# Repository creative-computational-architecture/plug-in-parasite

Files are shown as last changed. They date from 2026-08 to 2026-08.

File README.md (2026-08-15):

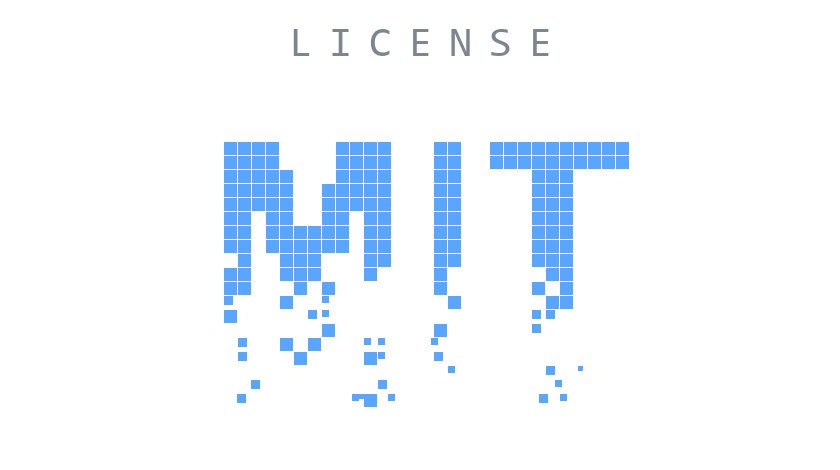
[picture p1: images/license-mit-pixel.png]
License: MIT


# Plug-in Parasite

*🇬🇧 English · [🇹🇷 Türkçe](README.tr.md)*

   

<p align="center">
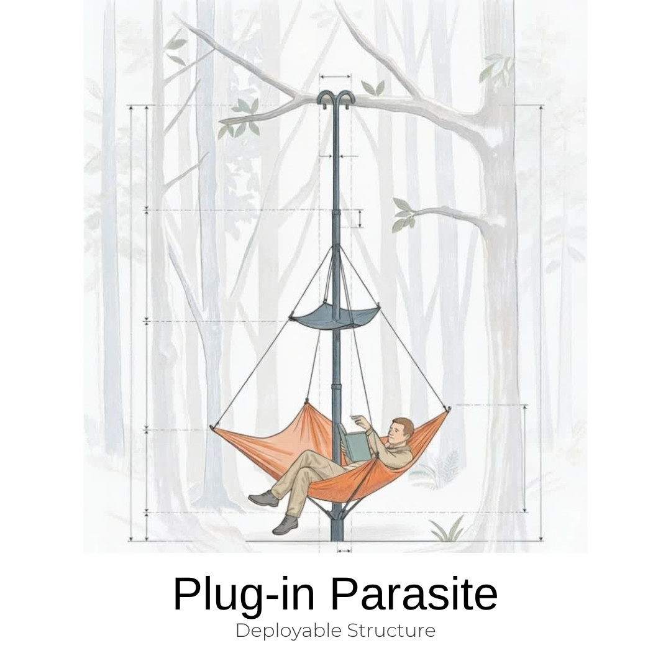
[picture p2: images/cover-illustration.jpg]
Plug-in Parasite — deployable structure, dimensioned cover illustration
  
</p>

> **The code in this repository is open-source under the [MIT License](LICENSE).** Fork it, run it, build on it. (Design assets, images and CAD models are CC BY-NC-SA 4.0 — see [License](#license).)

A parasitic, telescopic mast-tent — a portable shading/shelter structure that clamps onto urban street bollards or is staked into the ground. Folded, it is hand-carried. Deployed, it resembles a small ship's mast with two inverted-cone fabric canopies and a top sail.

**This is a real, open, in-development design — not a finished product and not a render exercise.** The concept and a physical maquette were made in a single night, then driven straight into a parametric model. It went through a full modelling-stack migration (Fusion 360 → Rhino 8 + Grasshopper) as the geometry logic matured, and the deployment film was curated down from ~40 AI video takes. We genuinely intend to build it — the socket, the telescopic mast, the whole thing — and the repository is shared in that spirit: to show the reasoning that got here, and to invite feedback, forks and manufacturing collaboration. Everything here is meant to keep evolving.

> **Authors / Context** — Creative Computational Architecture · Caglar Celik Architects (CCA). Concept and physical maquette developed 2026-05-16; parametric model built the same night with Claude as AI pair-modeller. Migrated to Rhino/Grasshopper 2026-05-17. Cinematic films generated with Seedance 2.0 / Kling 3.0. See [Tools & Credits](#tools--credits).
>
> *"Redefining space through computation."* — a design praxis studio working across analysis, mathematics, art, geometry, philosophy, aesthetics, architecture and technology.
>
> 📷 [Instagram @caglarcelikarchitects](https://www.instagram.com/caglarcelikarchitects) · [caglarcelik.works](https://caglarcelik.works)

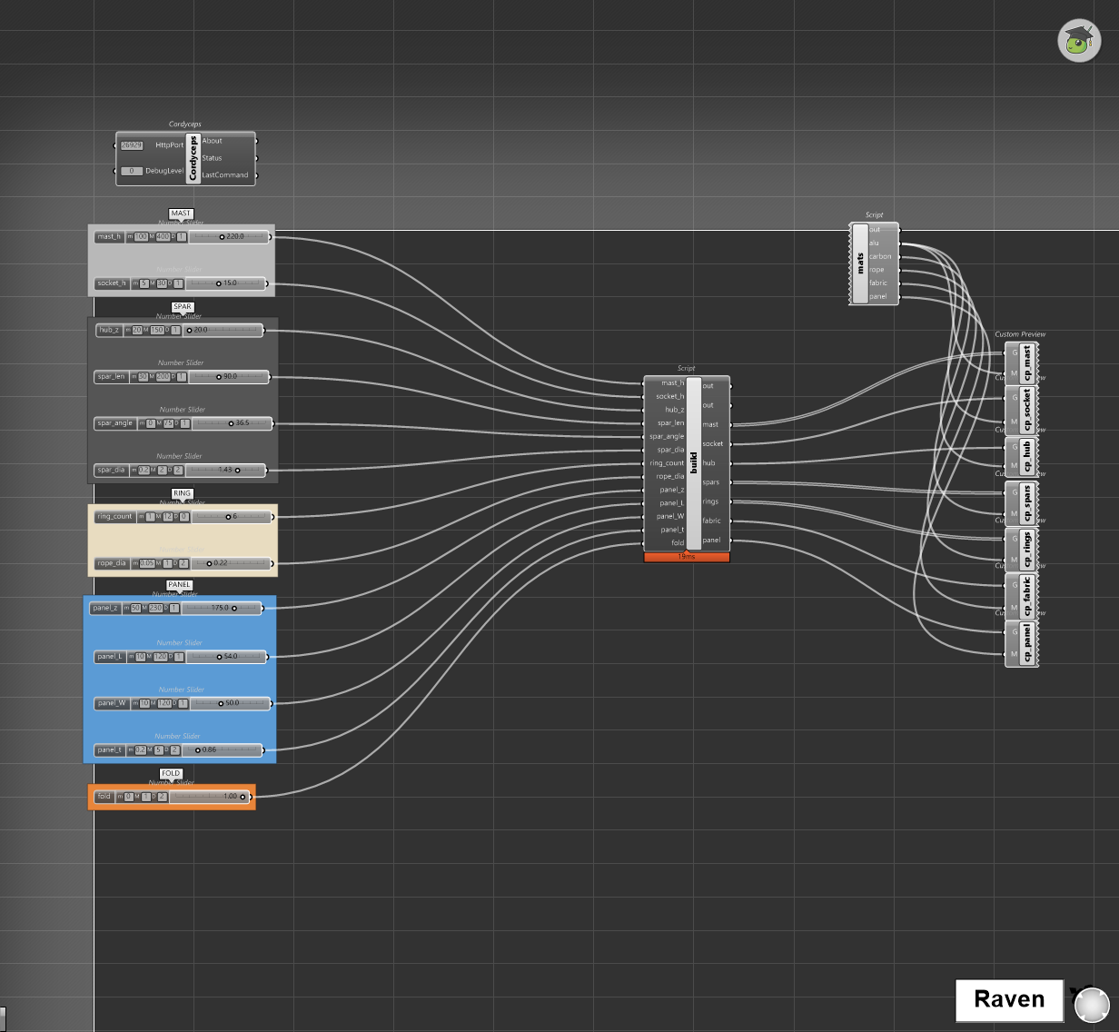
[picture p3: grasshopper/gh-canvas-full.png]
Grasshopper parametric definition — grouped parameters driving one build script and six geometry outputs


## Parametric System (Grasshopper)

The heart of this project is not the renders — it is the **parametric definition**. The whole structure is generated by a Grasshopper graph: a set of grouped sliders feed **one Python 3 build component** that emits six geometry sets. Change a slider, the whole shelter regenerates.

```
12 sliders (5 logical groups)                    →   build (Python 3)   →   6 geometry outputs
─────────────────────────────────────────────────────────────────────────────────────────────
MAST   : mast_h, socket_h                                                    mast    (3 telescopic tubes)
SPAR   : hub_z, spar_len, spar_angle, spar_dia                               socket  (bollard sleeve)
RING   : ring_count, rope_dia                                                hub     (spar clamp)
PANEL  : panel_z, panel_L, panel_W, panel_t                                  spars   (4 × swept up-and-out)
FOLD   : fold (0 = packed → 1 = deployed)                                    rings   (rope storage cage)
                                                                             panel   (diamond solar panel)
```

| | |
|---|---|
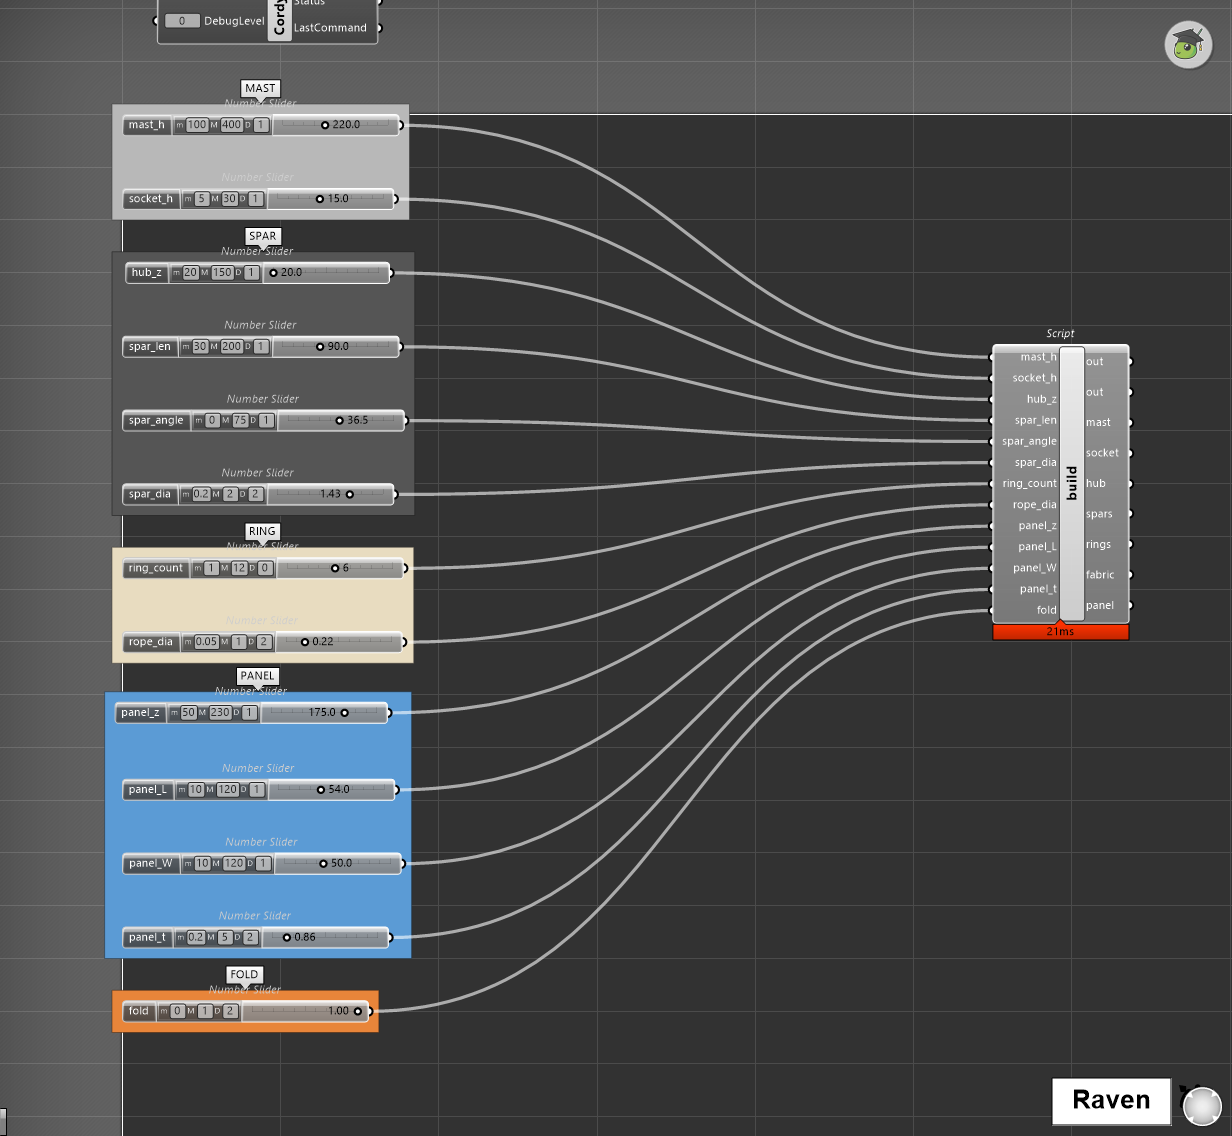
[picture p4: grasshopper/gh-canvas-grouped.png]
Colour-grouped parameter clusters
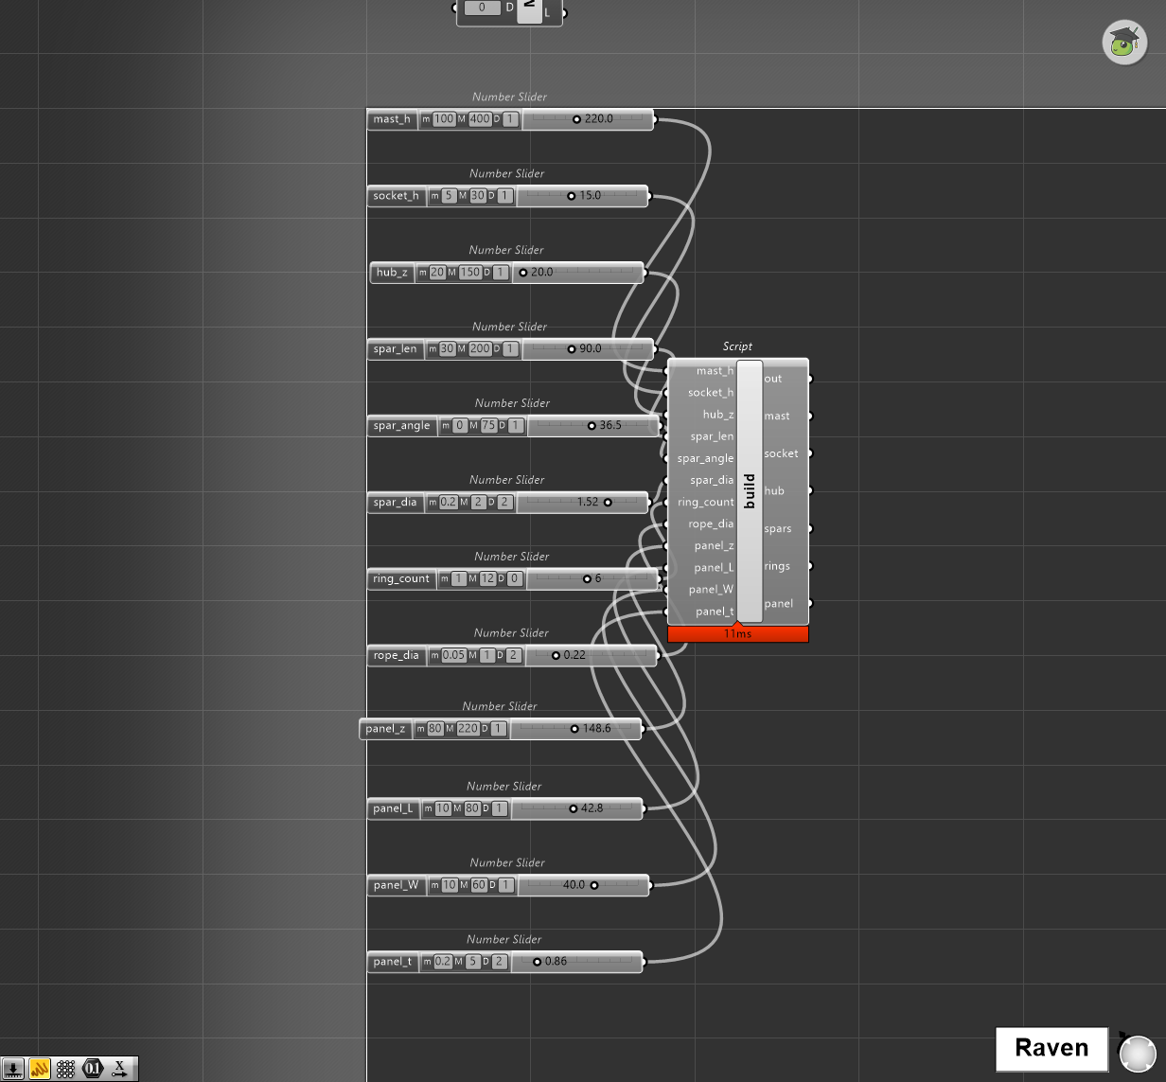
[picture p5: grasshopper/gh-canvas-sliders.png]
Slider column feeding the build component
|  |  |
| **Logical groups** — MAST / SPAR / RING / PANEL / FOLD, colour-coded on the canvas. | **One build component** — every slider wires into a single Python 3 script that returns the whole assembly. |

**Why it's built this way (the reasoning that got here):**

- **One driver, one script.** Rather than a sprawling web of native components, the geometry lives in a single readable Python 3 build script. The canvas stays legible; the *algorithm* carries the complexity. The per-stage logic is broken out for reference in [`cinematic/scripts/components/`](cinematic/scripts/components) — mast, hook, hub, spars, fabric hammock, panel canopy, storage rings, rigging ropes, carry strap.
- **A single `fold` parameter collapses the whole thing.** `fold` (0 → 1) is the deployment state: at 0 everything is packed inside the socket; at 1 it is the full 2.3 m rig. This is what makes it a *deployable* structure and not just a static model.
- **The design changed as the model matured — and the model shows it.** Two V1 ideas were deliberately replaced in V2, driven by the parametric work itself:
  - the rigid **upper fabric canopy → a diamond solar panel** (with a boolean-diff Ø30 mm mast hole);
  - the single-perimeter **diamond storage frame → a multi-ring "Chinese-lantern" cage** (`ring_count`, 1–12).
- **Edited programmatically.** The Grasshopper graph is driven by code through [Cordyceps](https://github.com/brookstalley/cordyceps), a Rhino 8 automation bridge — parametric edits are made programmatically, not by hand-dragging wires. This is the studio's tell: architecture built like software.

> Open `PlugInParasite.gh` in Rhino 8 Grasshopper to drive it live. `PlugInParasite.3dm` is the companion Rhino document.

---

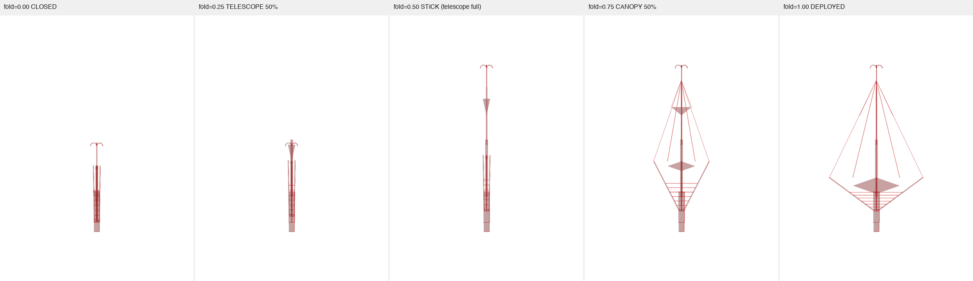
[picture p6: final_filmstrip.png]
Parametric fold sequence — fold 0 (closed) to 1 (deployed)


*One parameter, `fold`, drives the entire structure from packed to deployed:*
**`0.00` CLOSED → `0.25` TELESCOPE → `0.50` STICK → `0.75` CANOPY → `1.00` DEPLOYED.**

The same states, rendered — the wireframe above is not a drawing of an idea, it is the actual model output; below, the identical geometry with materials:

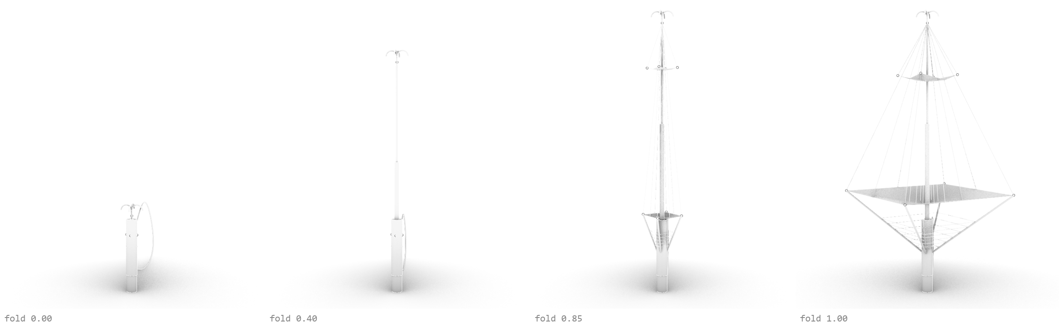
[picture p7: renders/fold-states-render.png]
Fold states rendered — white studio renders of the same four deployment states


---

## Deployment

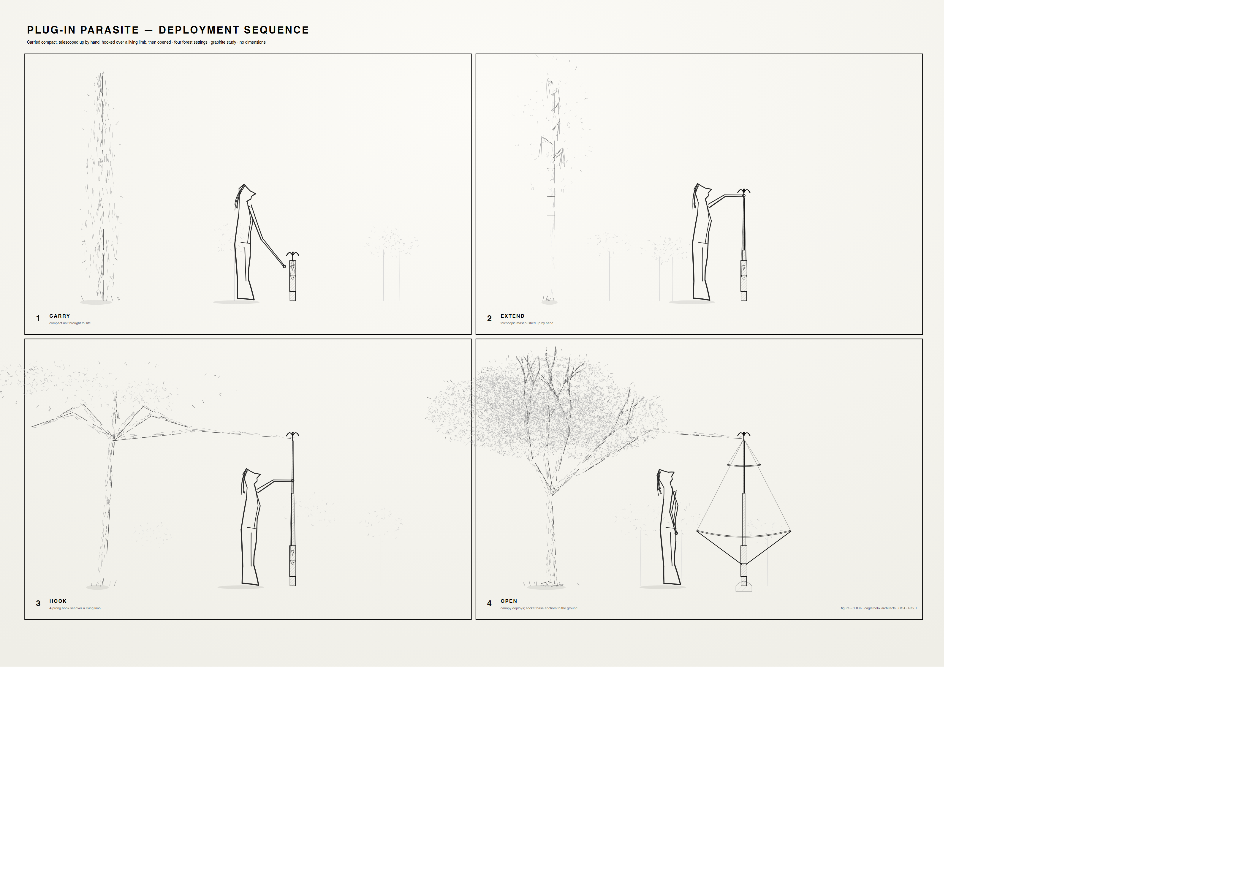
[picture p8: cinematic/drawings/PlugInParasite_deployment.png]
Deployment sequence — carry, extend, hook, open


*Hand-carried and compact → telescoped up by hand → hooked over a limb or plugged onto a bollard → canopy opened. One `fold` parameter drives the whole transition (see above).*

---

## Concept

The structure is designed around three states:

1. **Folded** — diamond-shaped, mast collapsed inside the socket, fabrics packed around the core. Hand-bag scale. *(the `fold=0` state)*
2. **Plugged onto a bollard** — the open base sleeve is dropped over a Ø80–100 mm street bollard, then the mast is telescoped upward and the canopies open. *Urban parking mode.*
3. **Staked into ground** — a pointed adapter screws into the base sleeve and is driven into soil. *Camping mode.*

The signature form is a **stack of two inverted cones** ("martini glass"): the lower wide canopy throws ground-level shade; the upper tier (now a solar panel) echoes a square-rigged ship's topsail. A small rectangular topsail and a pennant cap the rig.

<p align="center">
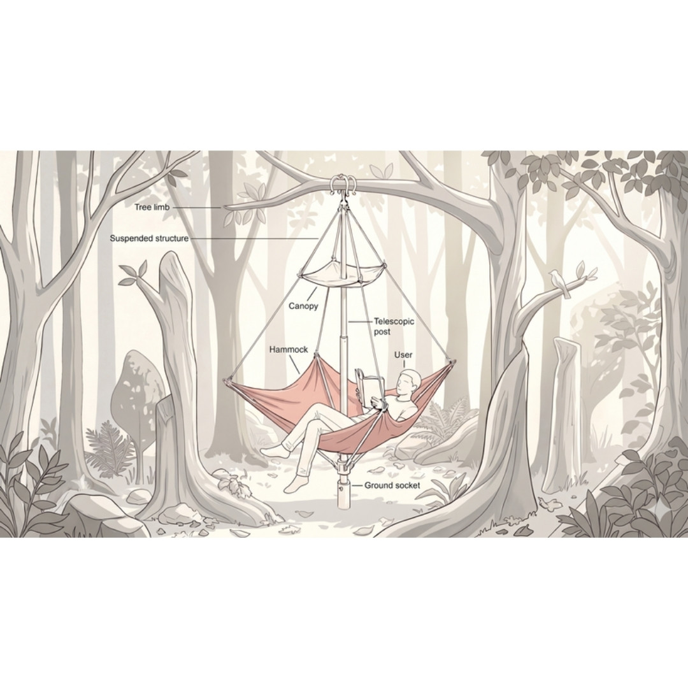
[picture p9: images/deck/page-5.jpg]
Annotated illustration — hammock, canopy, telescopic pole and ground socket labelled in the forest scene
  
</p>

*The inhabited state, annotated: hammock slung between the four spars, canopy above, telescopic pole, ground socket.*

---

## Components (Deployed)

Bottom-up, as generated by the Grasshopper build script:

| # | Component | Driven by | Description |
|---|---|---|---|
| 1 | **Socket** | `socket_h` | Two-bore sleeve: lower bore grips a Ø90 mm bollard, upper bore accepts the bottom mast segment. |
| 2 | **Mast** | `mast_h` | 3 telescopic aluminium tubes, OD Ø32 → Ø25 → Ø19 mm, 80 mm overlap per joint, fully extended 2.2 m. |
| 3 | **Hub** | `hub_z` | Single clamp hub on the mast that carries the four spars. |
| 4 | **Spars** | `spar_len`, `spar_angle`, `spar_dia` | Four rods springing **up and out**; tip reach sets the canopy footprint. |
| 5 | **Rings** | `ring_count`, `rope_dia` | 1–12 horizontal rope loops between adjacent spar tips — the "Chinese-lantern" storage cage. |
| 6 | **Panel** | `panel_z`, `panel_L/W/t` | Diamond solar panel with a boolean-diff Ø30 mm mast hole — replaced the V1 rigid upper canopy. |

Total deployed height ≈ 2.3 m. Folded target ≈ 0.7 m × 0.4 m × 0.15 m (hand-carry).

---

## Reference Material

The design started physical: a bamboo-and-thread maquette and a whiteboard full of iterations, the same night as the first model.

| | |
|---|---|
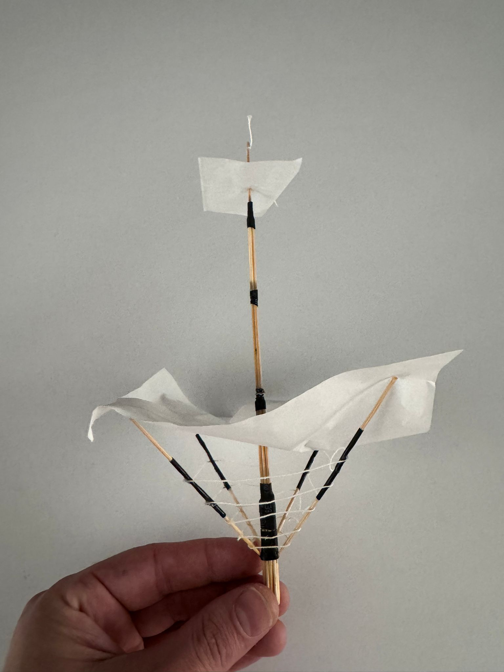
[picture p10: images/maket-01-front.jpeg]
maquette front
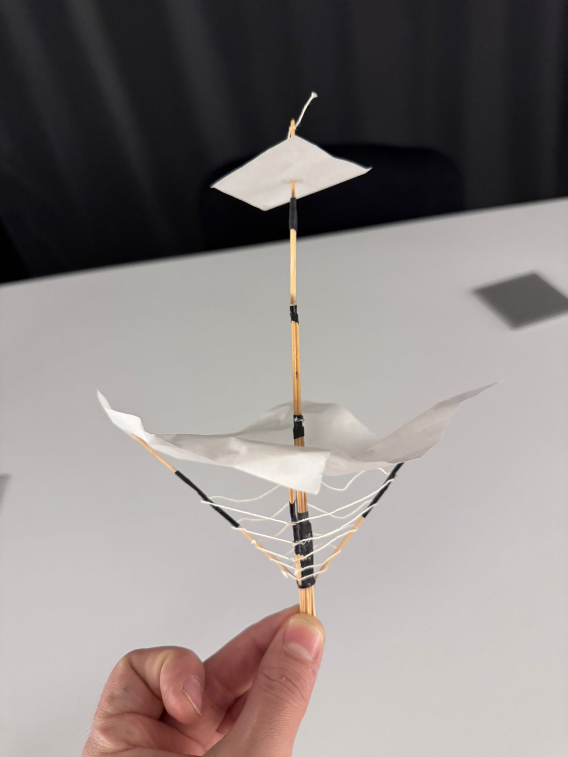
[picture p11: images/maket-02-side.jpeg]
maquette side
|  |  |
| Physical maquette — bamboo skewers, thread rigging, tissue-paper fabric. | Side view showing both canopies and the topsail. |
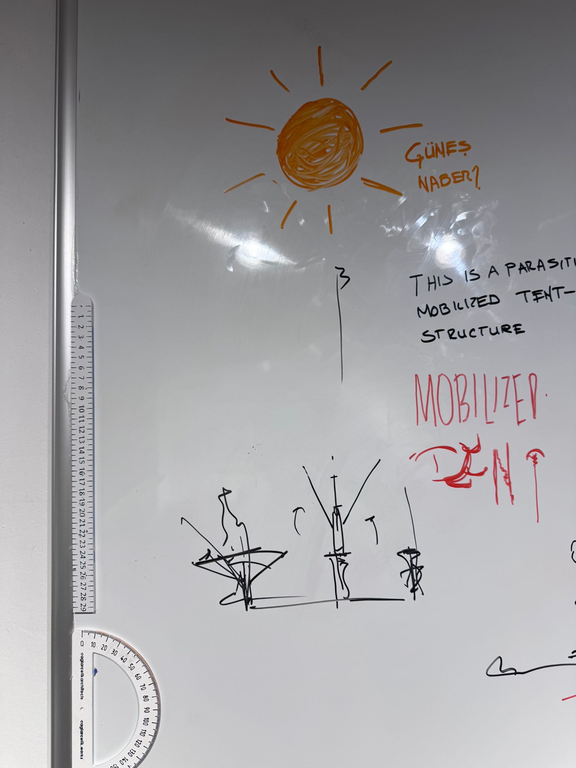
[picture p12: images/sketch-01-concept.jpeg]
whiteboard 1
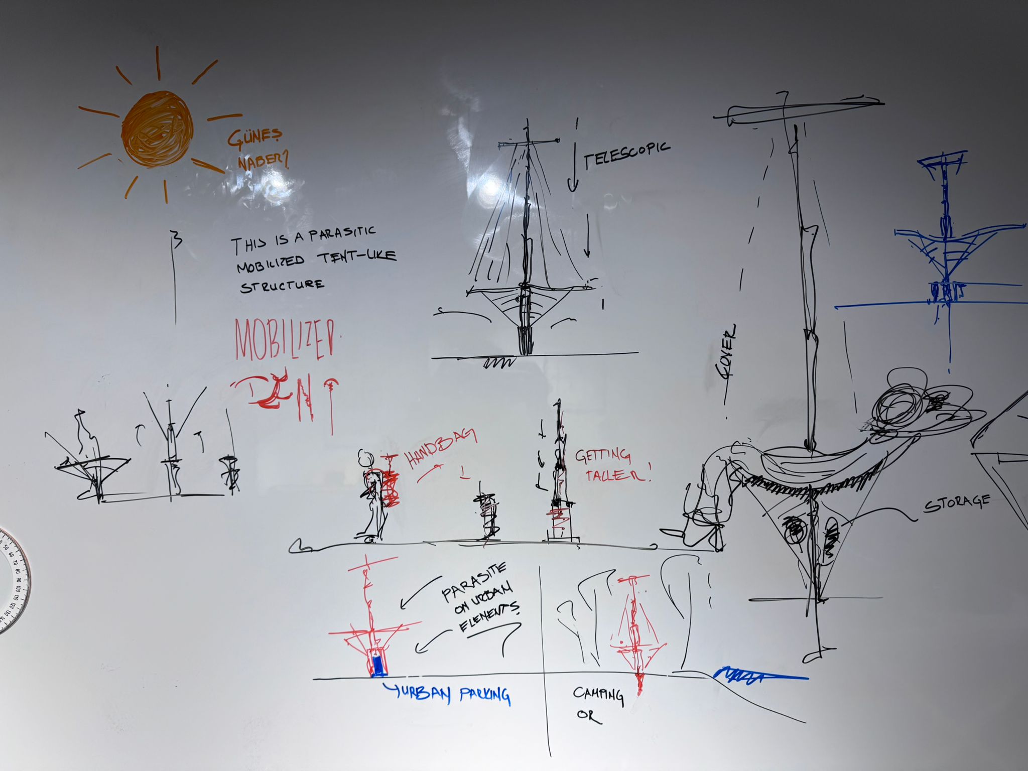
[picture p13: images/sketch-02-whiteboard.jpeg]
whiteboard 5
|  |  |
| Concept sketches: "Mobilized parasitic tent-like structure". | Full whiteboard with all the iterations. |
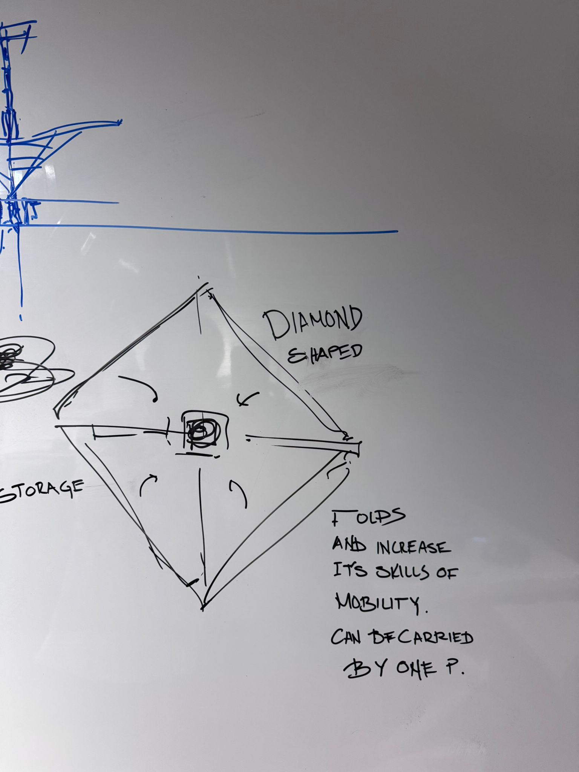
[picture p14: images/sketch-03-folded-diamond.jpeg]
diamond folded
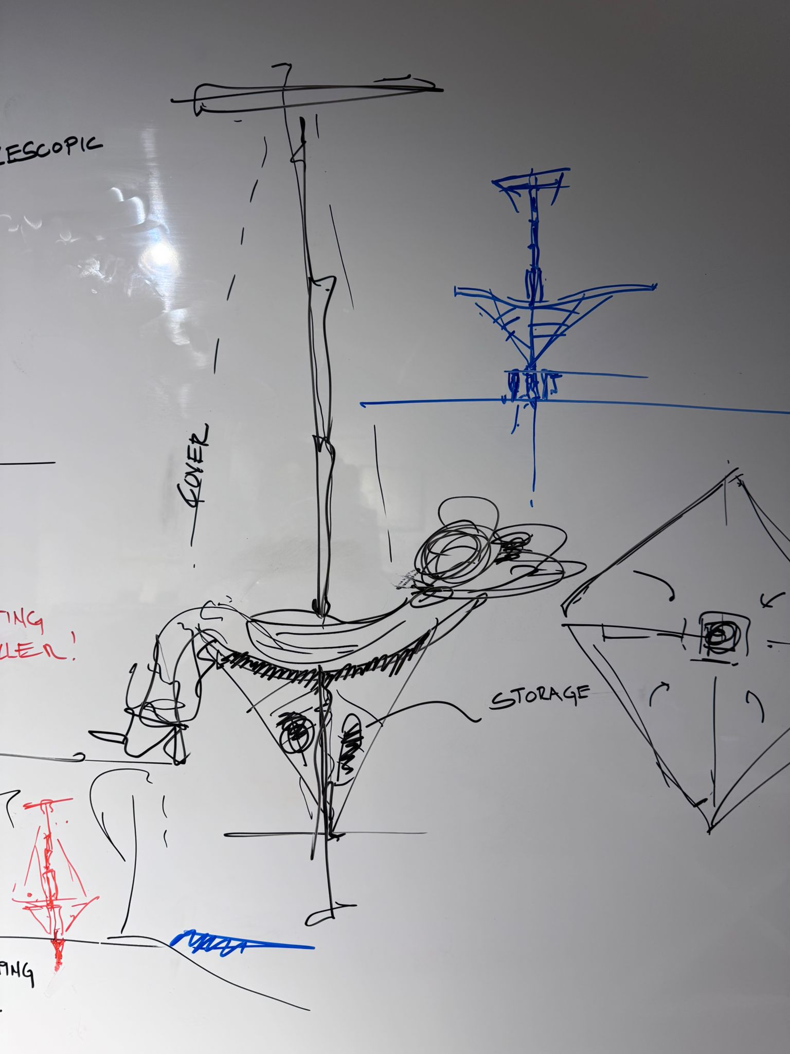
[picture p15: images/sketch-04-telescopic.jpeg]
telescopic detail
|  |  |
| Folded "diamond shape" state, with storage at the core. | Telescopic detail and rigging plan. |
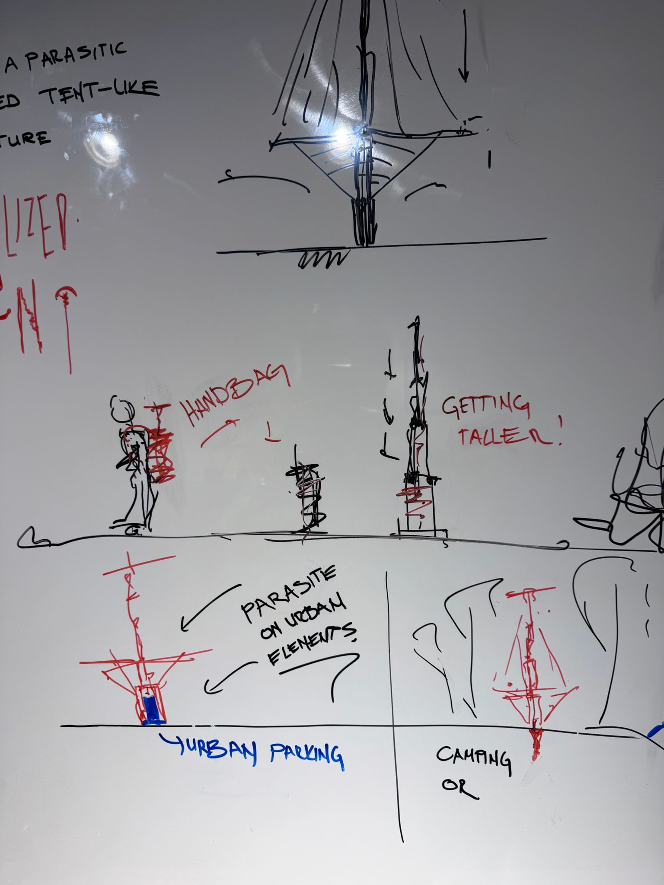
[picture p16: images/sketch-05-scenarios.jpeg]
urban + camping modes
|  |  |
| "Handbag → getting taller → parasite on urban elements / camping". | |

---

## Films

AI-cinematic shorts of the deployment sequence, built from the parametric model as reference imagery (image-to-video). These are the curated survivors of ~40 generations across Seedance 2.0 and Kling 3.0 — the shot list, prompts and edit pipeline are in [`cinematic/docs/`](cinematic/docs). Click to play on GitHub.

<p align="center">
  <a href="cinematic/films/PlugInParasite_process_reel.mp4">
    Process reel preview — renders, parametric canvas, illustrated storyboard
  </a>
</p>

*The process reel, playing inline — renders → parametric Grasshopper canvas → illustrated storyboard. Click it for the full-quality MP4 with sound.*

| File | What it shows |
|---|---|
| [`films/PlugInParasite_process_reel.mp4`](cinematic/films/PlugInParasite_process_reel.mp4) | **The process reel** — renders → parametric Grasshopper canvas → illustrated storyboard, in 20 seconds |
| [`films/PlugInParasite_deployment_FINAL_9x16.mp4`](cinematic/films/PlugInParasite_deployment_FINAL_9x16.mp4) | **Master cut** — full deployment story, vertical 9:16 |
| [`films/PlugInParasite_deployment_BLACK_v2_smooth_9x16.mp4`](cinematic/films/PlugInParasite_deployment_BLACK_v2_smooth_9x16.mp4) | Black carbon-fibre variant, smoothed master |
| [`films/PlugInParasite_WHITEFOAM_9x16.mp4`](cinematic/films/PlugInParasite_WHITEFOAM_9x16.mp4) | White-foam architectural maquette style |
| [`films/PlugInParasite_COVER_1960s_anim.mp4`](cinematic/films/PlugInParasite_COVER_1960s_anim.mp4) | Animated 1960s-style illustrated cover |
| [`films/PlugInParasite_annotated_walkthrough.mp4`](cinematic/films/PlugInParasite_annotated_walkthrough.mp4) | Annotated 3D component walkthrough — hook, panel, hammock, socket + telescopic mast (Turkish captions) |
| [`clips/`](cinematic/clips) | Individual shots: CARRY → SETDOWN → EXTEND → HOOK → OPEN → INHABIT → POV → FINALE |

### Presentation pages

The same story told across six media — cover illustration, photoreal film still, paper-craft maquette, product states, annotated scene, and the physical maquette on the whiteboard wall. Auto-advancing; stills in [`images/deck/`](images/deck).

<p align="center">
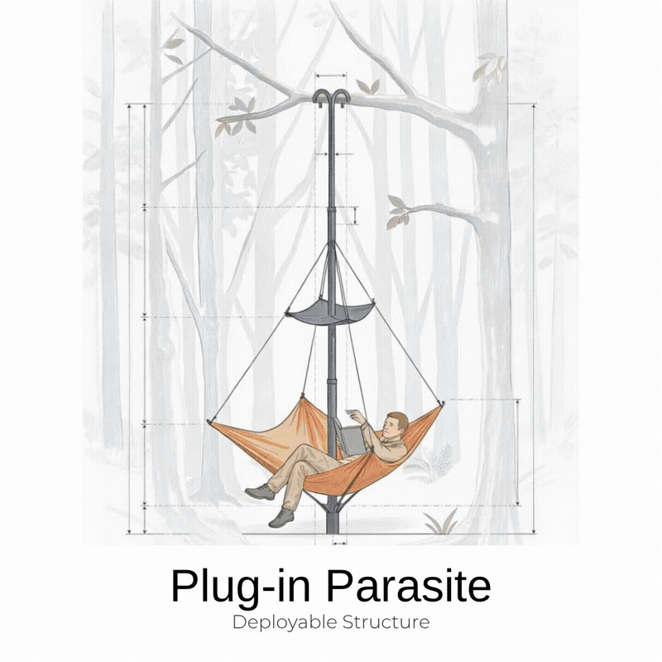
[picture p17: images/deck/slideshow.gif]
Presentation slideshow — six pages cycling automatically
  
</p>

---

## Renders & Drawings

Secondary to the parametric system, but included for reference: Fusion viewport captures and generated technical drawings (section 1:20, deployment sheet, branch detail — SVG/PNG/DXF plus the Python generators that draw them, in [`cinematic/drawings/`](cinematic/drawings)).

| Front | Iso | Right |
|---|---|---|
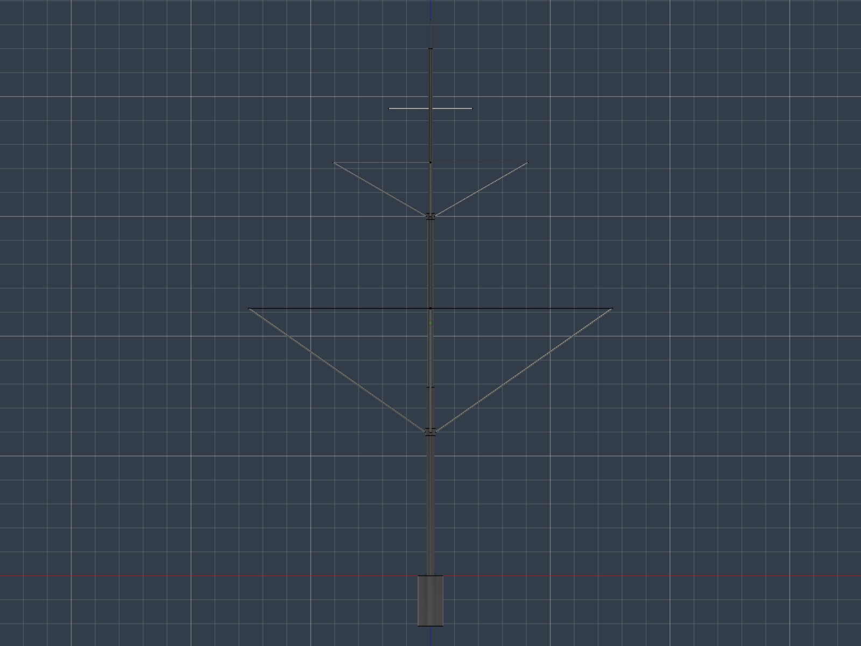
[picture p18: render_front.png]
front
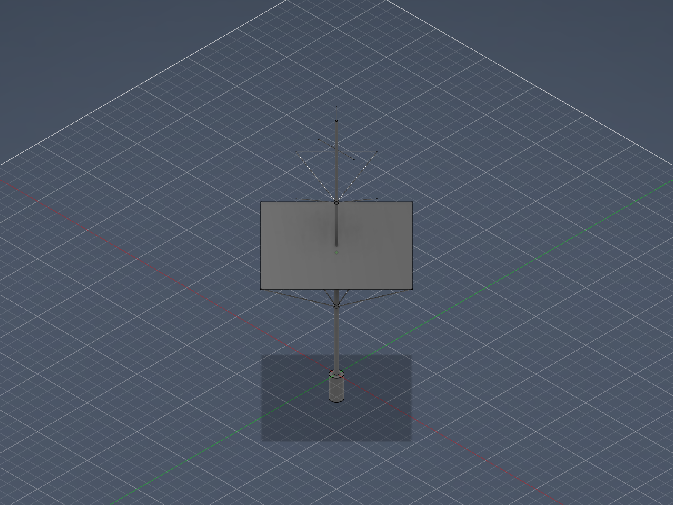
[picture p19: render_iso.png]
iso
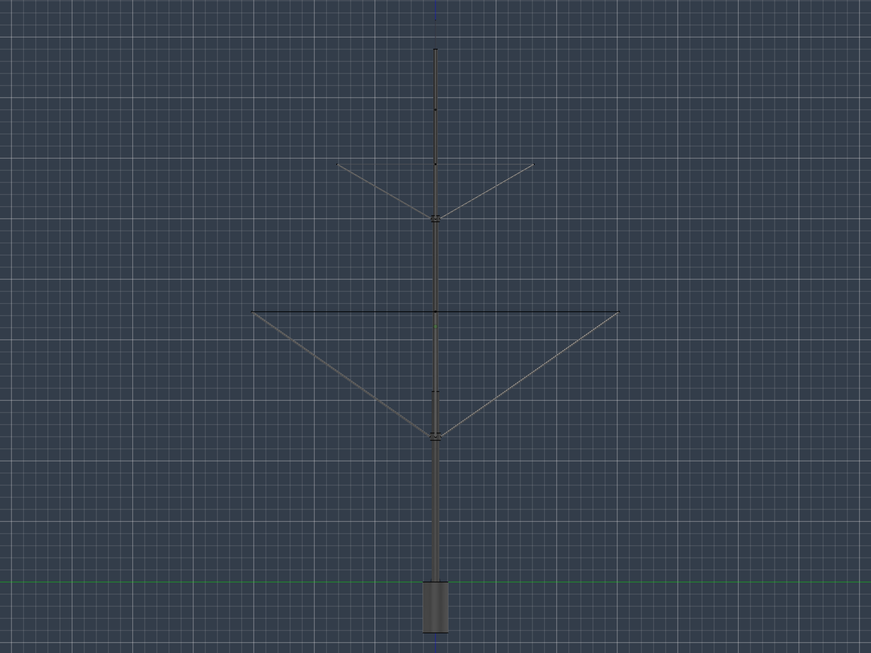
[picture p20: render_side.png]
side
|  |  |  |

---

## Parameters (reference values)

Current slider ranges and defaults on the Grasshopper canvas:

| Group | Slider | Range | Default |
|---|---|---|---|
| MAST | `mast_h` | 100–400 | 220 |
| MAST | `socket_h` | 5–30 | 15 |
| SPAR | `hub_z` | 20–150 | 20 |
| SPAR | `spar_len` | 30–200 | 90 |
| SPAR | `spar_angle` | 0–75° | 36.5 |
| SPAR | `spar_dia` | 0.2–2 | 1.45 |
| RING | `ring_count` | 1–12 | 6 |
| RING | `rope_dia` | 0.05–1 | 0.22 |
| PANEL | `panel_z` | 80–220 | 148.6 |
| PANEL | `panel_L` | 10–80 | 54 |
| PANEL | `panel_W` | 10–60 | 40 |
| PANEL | `panel_t` | 0.2–5 | 0.86 |
| FOLD | `fold` | 0–1 | 1 |

The Fusion V1 model exposes a larger set of 36 user parameters (mast tube diameters, wall thicknesses, sail rig, catenary rigging sag, etc.) — see [`cinematic/docs/GEOMETRY_SPEC.md`](cinematic/docs/GEOMETRY_SPEC.md) and `build_fusion_model.py`.

---

## Files

| Path | Purpose |
|---|---|
| `PlugInParasite.gh` | **Live parametric system** — Grasshopper definition (open in Rhino 8) |
| `PlugInParasite.3dm` | Companion Rhino 8 document |
| `PlugInParasite.f3d` | Archival — Fusion 360 V1 (36 parameters) |
| `PlugInParasite.step` | Cross-CAD STEP export (Rhino, SolidWorks, FreeCAD, …) |
| `build_fusion_model.py` | Standalone Fusion script that recreates the V1 model from scratch |
| `grasshopper/` | Canvas screenshots of the parametric definition |
| `cinematic/scripts/` | Per-stage GHPython component logic (the fold/deploy rig) |
| `cinematic/films/`, `clips/`, `concept_boards/` | Cinematic shorts, individual shots, AI concept boards |
| `cinematic/drawings/` | Technical drawings (SVG/PNG/DXF) + Python generators |
| `cinematic/docs/` | Geometry spec, storyboard, AI shot prompts, edit pipeline |
| `render_*.png`, `final_filmstrip.png` | Fusion viewport captures |
| `images/` | Source sketches + maquette photographs |

---

## Reproducing the Model

**Grasshopper (live):** open `PlugInParasite.gh` in Rhino 8, adjust any slider, geometry regenerates through the build component.

**Fusion V1 (from scratch):**

1. Fusion 360 → **File ▸ New Design**.
2. **Utilities ▸ ADD-INS ▸ Scripts and Add-Ins** (`Shift+S`).
3. Scripts tab → **`+`** → browse to `build_fusion_model.py` → **Run**.
4. The full model — parameters, all components, all bodies — appears in a few seconds.

---

## Roadmap (open — contributions welcome)

- **V2 — Folded state polish.** Verify the `fold=0` packed configuration reads as a clean hand-carry volume.
- ~~**Grasshopper migration.**~~ ✅ done — live parametric source of truth.
- ~~**Cinematic film.**~~ ✅ done — see [Films](#films).
- **V2 — Upper rigging & fabric drape.** Port the sail rig and lower-canopy fabric from the Fusion V1 into the Grasshopper script.
- **V3 — Cloth simulation.** Replace rigid loft surfaces with a draped cloth sim (Marvelous Designer / Houdini → back into GH).
- **V3 — FEA on socket.** Clamp force on the bollard and lateral stiffness under wind load.
- **Prototype (the real goal).** CNC-mill the aluminium socket and hubs; 3D-print hub clamp jaws; source carbon rod and rip-stop fabric; build and test a physical unit.

If you want to help make it real — manufacturing, materials, FEA, or just ideas — open an issue.

---

## Tools & Credits

Built with — and credit to — the following:

| Tool | Role |
|---|---|
| [Rhino 8](https://www.rhino3d.com/) + Grasshopper | Parametric geometry engine — the live model |
| [Cordyceps](https://github.com/brookstalley/cordyceps) | Rhino 8 automation bridge — programmatic Grasshopper editing |
| [Autodesk Fusion 360](https://www.autodesk.com/products/fusion-360/) | V1 solid model (36 parameters) |
| Claude / Claude Code (Anthropic) | AI pair-modeller — Python build logic, drawing generators, docs |
| [Higgsfield](https://higgsfield.ai/) | AI video generation platform |
| Seedance 2.0 · Kling 3.0 | Image-to-video models for the cinematic shots |
| Python 3 · ffmpeg | Geometry scripts and film edit pipeline |

Physical maquette, concept and design direction: Caglar Celik Architects.

---

## License

<p align="center">
  <picture>
    <source media="(prefers-color-scheme: dark)" srcset="images/brand/cca-mono-dark.svg">
    Creative Computational Architecture — CCA
  </picture>
  &nbsp;&nbsp;&nbsp;&nbsp;
  License: MIT
</p>

- **Code** (Python scripts, Grasshopper definition): [MIT](LICENSE).
- **Design, images, videos and CAD models**: [CC BY-NC-SA 4.0](https://creativecommons.org/licenses/by-nc-sa/4.0/) — share and adapt with attribution, non-commercial. For commercial use or manufacturing, contact the studio.

© 2026 Creative Computational Architecture — Caglar Celik Architects (CCA)

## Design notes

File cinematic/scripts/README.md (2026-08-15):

# Animation Rig Scripts (Rhino 8)

Python components that build the fold/deploy animation rig for the Track B clay renders.
Each file in `components/` is one stage of the parametric fold logic — mast, hook, hub,
spars, fabrics, straps — driven by a single `f_open` parameter (0 = folded, 1 = deployed).

## Usage

1. Open `PlugInParasite.3dm` in Rhino 8.
2. Run `setup_views.py` via `_-RunPythonScript` — it creates the named views
   (B1–B5 camera setups) used by the shot list.
3. Load the `components/*.py` files as GhPython components in Grasshopper
   (numbered in dependency order), wire `f_open` to a slider or animation driver.
4. Render frames per the edit pipeline in [`../docs/edit_pipeline_v2.md`](../docs/edit_pipeline_v2.md).

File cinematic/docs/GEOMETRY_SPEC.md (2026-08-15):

# PLUG-IN PARASITE — STRUCTURAL GEOMETRY SPEC (canonical, locked)

**Source of truth:** live Grasshopper model `PlugInParasite.gh` (fold slider GUID
`13550bea-2222-4361-a414-2a1fd2069271`; deployed = fold **1.0**). Measured
2026-06-24 from exact slider reads + baked-geometry bounding boxes.

> **RULE:** every render / AI image MUST match these proportions. Do **not**
> redesign, do **not** change any lengths, do **not** move GH sliders to "scale"
> the object for a scene — scale only in the prompt. The repeated failures came
> from (a) soft/ambiguous references and (b) ignoring the aspect ratio below.

Coordinate system: **Z-up, centimetres**, mast on the Z axis (x = y = 0), ground
plane at z = 0.

---

## GH parameters (deployed)

| param | value | meaning |
|---|---|---|
| `mast_h` | **220 cm** | telescopic mast full height |
| `socket_h` | **15 cm** | ground-anchor sleeve depth (z −15→0) |
| `panel_z` | **175 cm** | top canopy panel height |
| `panel_L × panel_W` | **54 × 50 cm** | canopy panel size |
| `panel_t` | 0.86 cm | canopy thickness |
| `spar_len` | **90 cm** | radial spar length |
| `spar_angle` | **36.5°** | spar splay (deployed) |
| `spar_dia` | 1.43 cm | spar tube diameter |
| `ring_count` | **6** | storage rings |
| `rope_dia` | 0.22 cm | rigging rope diameter (very thin) |
| `hub_z` | 20 | hub rise param |
| `fold` | **0 = folded · 0.5 = extended (canopy closed) · 1 = deployed** |

---

## Vertical stack (deployed, ground = z0)

1. **Socket** — z −15 → 0. Short ground-anchor sleeve the mast plugs into.
   **THE ONLY GROUND-CONTACT POINT, directly beneath the mast.** Nothing else
   touches the earth.
2. **Telescopic mast** — z 0 → 220. Slim vertical pole, **3 nested segments
   narrowing upward**: base seg ≈ Ø10 cm (z 0–50), mid ≈ Ø4 (z 42–135), top ≈ Ø2
   (z 127–220). Brushed aluminium.
3. **Bottom bed (hammock)** — 4 corners at **z 73.5**, reaching **±76.3 cm** on
   the X and Y axes (diamond / rotated-45° square, ~108 cm side). Warm-red
   (`#C43D1C`) ripstop fabric. Sits in the **lower third** (30 % of total height).
4. **6 storage rings** — z ≈ 19 → 50. Concentric horizontal rope rings around the
   lower mast, **below** the bed.
5. **Top canopy panel** — z **175**, **54 × 50 cm** near-horizontal flat cloth,
   upper third (70 % up). Rigging nodes at its 4 edge mid-points.
6. **Hook spire** — z 220 → 233.6. Central spire topped by **4 curved prongs**
   that splay to ±10.6 cm (**span ≈ 21 cm, ≈ 13 cm tall**). Steel. Hooks over a
   tree branch. *In renders show it clearly / slightly emphasised — it reads too
   small otherwise (user note).*

---

## PROPORTIONS / ASPECT RATIO — **LOCK THESE**

- Bounding box: **152.6 (W) × 152.6 (D) × 248.6 (H) cm**.
- **Front silhouette aspect  W : H ≈ 1 : 1.63** — the structure is **~1.6× TALLER
  than it is wide. Distinctly vertical / portrait.** Never squat.
- Mast (220) ≈ **1.44 × bed width** (152.6).
- Heights as fraction of total: bed **30 %**, canopy panel **70 %**, hook **100 %**.
  **Widest point = the bed** (lower third).
- Silhouette read: a slim vertical mast carrying a tall slender **DIAMOND / KITE**
  — rigging fans from the hook (top) down-and-out to the 4 bed corners (widest,
  lower third), then tapers back in to the socket.

---

## Rigging — **STRAIGHT tension lines (tensegrity)**

- **12 ropes**, very thin (Ø 0.22), from the spire/hook down to the canopy-panel
  nodes and the 4 bed corners.
- **Ropes are STRAIGHT, taut, in tension. Never curved, never slack, never
  lengthened.**
- Where a rope meets a **canopy-panel node, its axis does NOT change** — the line
  continues straight through the node (no kink / no direction break).

---

## Membrane (bed) sag

- The warm-red bed is a **shallow catenary** slung between the 4 corners at z 73.5.
- Ideal look = a **soft, comfortable sag** (like the first hero, occupied) — centre
  drops ≈ **25–40 cm** below the corner line. **NOT taut/flat, NOT extreme.**

---

## Recurring AI mistakes — DO NOT REPEAT

- Hook → 2-prong / anchor / too small. **Must be 4 splayed curved prongs, clearly
  visible.**
- Ropes → curved / slack / lengthened. **Keep straight & original length; no kink
  at nodes.**
- Ground contact → drifting off the mast. **Socket only, under the mast.**
- Proportions → squat / wide. **Hold 1 : 1.63 tall; slim mast taller than the bed
  is wide.**
- Storage rings dropped. **Keep all 6.**
- Soft/ambiguous reference (Arctic white-on-white). **Use the edged Technical
  render on grey as the primary lock.**

---

## Canonical reference renders — `geometry_ref/`

| file | state | use |
|---|---|---|
| `deployed_edged.png` | deployed, Technical **edged** (crisp boundaries) | **primary geometry lock** |
| `deployed_clay.png` | deployed clay on grey | solid form |
| `extended_clay.png` | fold 0.5 (mast up, canopy closed) | EXTEND / HOOK beats |
| `folded_clay.png` | fold 0 (compact column + 4-prong hook + strap + socket) | CARRY / SETDOWN beats |

Render recipe: Rhino display mode **Arctic** or **Technical** (edged) ·
background solid `#5D6B7A` · sun alt 40°/az 135° + skylight · `gh_document
capture_viewport` to a **non-Turkish path** (Turkish path fails). GH live preview
is NOT captured → **bake** the 9 geometry script components to a temp layer per
fold state, capture, then delete the layer and restore `fold` + show `PIP_compare`.

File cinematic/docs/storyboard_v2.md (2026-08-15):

# Plug-in Parasite — Cinematic Storyboard V2 (2026-05-28)

Updates the original `storyboard.md` for the current state: 10-component
GH canvas, V2.1 hammock, clay material on `#607080`, close-framing camera
(380,-180,280 → 0,0,120 lens 35mm), and a fresh 30s HERO render.

---

## What's already in `cinematic/shots_v2/`

| File | Source | Duration | Resolution | Notes |
|---|---|---:|---|---|
| `HERO_v11_30s.mp4` | render_queue_v2.py (550,-400,180) | 30s | 1280×720 | V12 close framing pending |
| `HERO_30s.mp4` (May 26) | V10 monolithic | 30s | 1280×720 | reference framing |
| `HERO_v4_30s.mp4` (May 26) | V10 earlier | 30s | 1280×720 | reference |
| `an1_rhino_animated.mp4` | Rhino animation export | 4s | 1500×1500 | square, user hand-animated |

> The "close-framing V12" render is in progress (background job
> `bfz2x1d3s`) — it will land at `cinematic/shots_v2/HERO_v12_30s.mp4`
> once ffmpeg composes the 720 PNGs.

## What's missing

- **Track A** (cinematic forest) — 3 atmospheric AI-generated shots
- **Final edit** — DaVinci timeline that interleaves Track A + clay
- **VO + music**

---

## Track A revised — 3 shots, ~$20 on Kling 2.0

**Bookend + hero structure-in-forest:**

```
0:00–0:05   A1  forest establishing               (empty, cinematic AI)
0:05–0:35   B   HERO_v12 30s deploy/retract cycle (clay)
0:35–0:40   A3  hero structure deployed in forest (image-to-video on
                                                   clay keyframe seed)
0:40–0:45   A2  pull-back forest reveal           (empty, cinematic AI)
```

Total **45 seconds**. Cinematic establishing → clay mechanics → hero
in nature → cinematic closure. A3 is the bridge that places the
parasol in its real environment; using image-to-video on a clay
keyframe locks the geometry so Kling doesn't hallucinate the structure
into something else.

If A3 is too hard or budget is tight, fall back to the simpler 3-cut
bookend (drop A3, total 40s) — `track_a_prompts_v2.md` Path 1 vs Path 2
section explains the trade-off.

### A1 — Forest establishing (0:00–0:05)

**Goal:** atmospheric setup. The viewer lands in a peaceful temperate
forest. No structure visible yet. A slow forward dolly draws them in.

**Tool:** Kling 2.0 (Pro), text-to-video.

**Prompt:**
```
Cinematic morning shot in a temperate deciduous forest. Soft sunlight
streaming through tall beech and oak trees, dappled light spots on
the forest floor. Wide-angle establishing shot. Slow forward dolly
movement, very gentle. Light mist near the ground. No people, no
animals. Realistic, just after sunrise. Cinematic depth of field,
shallow focus on a single tree trunk in foreground. Anamorphic lens
look, slight film grain. 16:9, 5 seconds.
```

**Negative:** people, person, human, figure, animals, deer, text, logo,
watermark, blur, overexposed, cartoon, illustration, drone shot.

**Output:** `shots_A/A1_forest_establishing.mp4` (1920×1080, 5s).

### A2 — Pull-back reveal (0:35–0:40)

**Goal:** scale + closure. The camera pulls back from a quiet forest
clearing where the deploy-then-retract cycle just happened. Empty,
serene, "just-departed" feeling. No structure required in this
shot — the cut before is the structure folding back into its bag.

**Prompt:**
```
Cinematic wide pull-back shot from forest clearing outward into a vast
quiet temperate forest. Slow continuous camera retreat. Late morning
light, golden tones, mist between distant trees. Empty clearing
visible center-frame. No people, no objects, no equipment. Realistic,
anamorphic, slight film grain. End on a still wide composition,
20-30% sky visible above tree line. 16:9, 6 seconds.
```

**Negative:** same as A1, plus "tent, camping equipment, structure,
tower, post."

**Output:** `shots_A/A2_pullback.mp4` (1920×1080, 6s — trim to 5s).

---

## Submission checklist for Kling

1. Account: <https://klingai.com> — starter pack ~$10 = 660 credit
2. Pro mode ~70 credit per shot. 2 shots × 3 attempts each = 420 credit
3. Settings per shot:
   - **Mode:** Pro
   - **Aspect:** 16:9
   - **Duration:** 5s (A1) or 6s (A2)
   - **Camera:** Forward Dolly (A1), Pull Back (A2)
   - **Style:** Cinematic
4. **Try 2-3 generations per shot, save all** — pick the best take in
   DaVinci, keep the others as reference.
5. **Download:** original quality MP4, no watermark (paid mode).

---

## Alternative: skip Kling entirely

If you want zero AI cost, the clay HERO is portfolio-ready as-is once
the V12 close-framing render lands. Add:
- 2-sec title card at start (project name + cca-architects)
- 2-sec end card (year + collaborators)
- Soft ambient music (Suno / Epidemic Sound)

Total ~34 sec, portfolio-grade, $0 AI spend.

---

## Files

- `storyboard.md` — original 6-cut hybrid plan (reference)
- `storyboard_v2.md` — this file
- `track_a_prompts.md` — prompts for full 3-shot version
- `track_b_shotlist.md` — clay shot inventory
- `vo_script.md` — EN voiceover + TR subtitle
- `edit_pipeline.md` — DaVinci + ffmpeg notes
- `shots_v2/HERO_v12_30s.mp4` — the new clay hero (in progress)
- `shots_A/` — empty, AI shots land here after Kling generation

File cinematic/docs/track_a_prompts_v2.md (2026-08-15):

# Track A Prompts V2 — paste-ready Kling submission

Three shots for the cinematic wrapper:

- **A1** — empty forest establishing (atmosphere setup, no structure)
- **A2** — empty forest pullback (closure, no structure)
- **A3** — **structure deployed in forest** (full description, hung from tree)

A1 and A2 are deliberately empty so Kling's hallucination risk stays
contained. A3 is the hero "in the wild" shot — it describes the
parasol explicitly: vertical mast, 4-prong curl hook at top hooking
around a tree branch, hanging hammock seat below, small flat canopy
above, tensile rigging ropes, storage ring frame around the lower
mast. Best run as **image-to-video** with a clay HERO keyframe as
the seed so Kling has the geometry locked in visually.

Total ~$15-25 at Kling Pro depending on how many re-rolls A3 needs.

> Rules across all three shots: **no people, no figures, no equipment**
> other than the parasol itself.

---

## A1 — Forest Establishing (5 seconds)

**Settings (klingai.com):**
- Mode: **Pro**
- Aspect: **16:9**
- Duration: **5s**
- Camera: **Forward Dolly Slow**
- Style: **Cinematic**

**Prompt:**
```
Cinematic morning shot in a temperate deciduous forest. Soft sunlight
streaming through tall beech and oak trees, dappled light spots on
the forest floor. Wide-angle establishing shot. Slow forward dolly
movement, very gentle. Light mist near the ground. No people, no
animals. Realistic, just after sunrise. Cinematic depth of field,
shallow focus on a single tree trunk in foreground. Anamorphic lens
look, slight film grain.
```

**Negative prompt:**
```
people, person, human, figure, animals, deer, text, logo, watermark,
blur, overexposed, cartoon, illustration, drone shot, top-down, snow
```

**Try count:** generate 3, pick best (mist consistency + dappled light
pattern matter most). Save the runners-up in `shots_A/A1_v01.mp4`,
`A1_v02.mp4`, etc. before deciding.

**Save as:** `cinematic/shots_A/A1_forest_establishing.mp4`

---

## A2 — Pull-back Reveal (6 seconds)

**Settings:**
- Mode: **Pro**
- Aspect: **16:9**
- Duration: **6s**  (trim to 5s in edit)
- Camera: **Pull Back**
- Style: **Cinematic**

**Prompt:**
```
Cinematic wide pull-back shot from forest clearing outward into a vast
quiet temperate forest. Slow continuous camera retreat. Late morning
light, golden tones, mist between distant trees. Empty clearing
visible center-frame. No people, no objects, no equipment. Realistic,
anamorphic, slight film grain. End on a still wide composition,
20-30% sky visible above tree line.
```

**Negative prompt:**
```
people, person, human, figure, animals, vehicles, text, logo,
watermark, drone shot, top-down, tent, camping equipment, structure,
tower, post, building, snow, rain
```

**Try count:** 3 generations. The "empty clearing center-frame" is the
hard constraint — if Kling hallucinates a structure in the middle,
re-roll.

**Save as:** `cinematic/shots_A/A2_pullback.mp4`

---

---

## A3 — Hero in Forest (5 seconds, image-to-video PREFERRED)

This is the shot where the AI needs to know what the structure is.
Two paths; **path 1 (image-to-video) is strongly preferred** because it
locks in the geometry from a real render.

### Structure description (used in BOTH paths)

The parasol is a minimalist white plaster-finish sculptural object:

- **Top:** a small 4-pronged curl hook in white pipe, like four
  question marks fanning outward, that wraps around a tree branch
  to suspend the entire assembly from above.
- **Vertical mast:** a slender 3-segment telescoping white cylinder
  running straight down from the hook, about 2.2 meters tall.
- **Just below the hook:** a small nearly-flat square white cloth
  canopy (about 40 × 30 cm) held taut by tensile ropes radiating
  from the hook above.
- **Middle of the mast:** a small white cylindrical hub from which
  four white spar pipes extend outward and slightly upward like an
  inverted umbrella, at about 35° from horizontal.
- **At the tips of the spars:** a large square hammock seat in
  taut white fabric, stretched between the four spar tips — like
  an architectural seat suspended in the air.
- **Around the lower mast:** horizontal rope rings forming a small
  storage frame.
- **Tensile rigging:** thin white ropes from the hook at the top
  down to the panel corners, spar tips, and edge midpoints —
  giving the whole assembly a sailboat-rigging appearance.

White plaster finish throughout. Soft skylight, shadow-only ground.

### Path 1 — Image-to-video on a clay keyframe (RECOMMENDED)

**Seed image:** pick a single frame from
`cinematic/shots_v2/HERO_v12_30s.mp4` where the structure is fully
deployed (around mid-video, 15 seconds in). Extract with:

```bash
ffmpeg -y -ss 15 -i cinematic/shots_v2/HERO_v12_30s.mp4 \
  -frames:v 1 cinematic/shots_A/A3_seed.png
```

Upload that PNG to Kling's image-to-video.

**Motion prompt (paste into Kling):**
```
A white minimalist sculptural object suspended from a high tree
branch in a quiet temperate forest clearing. The four-pronged hook at
the top grips the branch from above. Dappled morning sunlight
filtering through leaves overhead casts shifting light spots on the
clay-white surfaces. Subtle wind: the hammock fabric below sways
very gently, the small canopy above lifts and settles, the tensile
ropes vibrate softly. Dust particles drift in the sunbeams. Static
camera, locked off, slight handheld breath. Realistic, photographic,
shallow depth of field, anamorphic lens, 5 seconds.
```

**Negative prompt:**
```
people, person, human, figure, hands, arms, animals, deer, birds,
text, logo, watermark, structure changes shape, structure deforms,
structure spins, camera zoom, camera pan, drone shot
```

**Settings:** Pro, 16:9, 5s, Camera = Static, Style = Cinematic,
Image weight = high (so Kling preserves the structure faithfully).

**Try count:** 3. Watch for hammock distortion and hook hallucinations
into something else (often becomes a wind chime or lantern).

**Save as:** `cinematic/shots_A/A3_hero_in_forest.mp4`

### Path 2 — Text-only fallback (riskier, may hallucinate geometry)

If image-to-video isn't available or the seed approach fails, try
text-to-video with the full description:

```
A minimalist white plaster sculptural object suspended from a high
oak tree branch in a quiet temperate forest clearing. The object has
a small 4-pronged curl hook at the very top wrapping around the
branch like four question marks. Directly below the hook hangs a
slender 3-segment vertical white mast, about 2 meters long, with a
small flat square white canopy near the top. Mid-mast, four white
spars extend outward and slightly upward like an inverted umbrella,
with a large taut square white hammock fabric stretched between
their tips. Thin tensile ropes connect the hook down to every
attachment point. Dappled morning sunlight, subtle wind moving the
hammock and the leaves. Static camera. Realistic photographic
architectural product film aesthetic, shallow depth of field. 5
seconds, 16:9, anamorphic.
```

Same negative prompt as path 1. Expect 5-6 re-rolls; this is the
hardest shot to nail.

---

## Budget plan

| Item | Credit | USD |
|---|---:|---:|
| Kling starter pack | 660 | ~$10 |
| A1 × 3 generations (Pro) | 210 | (covered) |
| A2 × 3 generations (Pro) | 210 | (covered) |
| A3 × 3 generations image-to-video (Pro) | 240 | top-up needed |
| Buffer for A3 re-rolls | 300 | top-up needed |
| **Total** | **1160** | **~$20** |

A3 image-to-video runs a bit more credit per generation than text-to-
video (image weight processing). Budget two top-ups of $10 each in case
A3 needs 5-6 re-rolls.

---

## Acceptance criteria

A1 passes if:
- [ ] No human visible anywhere in 5 sec
- [ ] Forward dolly motion is smooth (no jitter)
- [ ] Dappled light pattern is consistent across the 5 sec
- [ ] Foreground tree trunk in focus, background bokeh

A2 passes if:
- [ ] Center frame stays empty (no structure hallucination)
- [ ] Pull-back is smooth and continuous (no jump cuts)
- [ ] End frame composition can hold a 1-2 sec still (for outro
      typography to land)
- [ ] Sky visible at the top of the frame at the end

A3 passes if:
- [ ] Structure shape stays close to the seed image (hook + mast +
      hammock + canopy + spars + rigging all preserved)
- [ ] Hook is wrapping around the tree branch from above (not floating
      next to it)
- [ ] No people / hands appear
- [ ] Hammock swing is subtle (a few cm of motion, not whipping)
- [ ] Lighting is dappled forest morning, not harsh studio or sunset

---

## Once both shots are downloaded

Use `cinematic/edit_pipeline_v2.md` ffmpeg concat recipe:

```bash
ffmpeg -y \
  -i cinematic/shots_A/A1_forest_establishing.mp4 \
  -i cinematic/shots_v2/HERO_v12_30s.mp4 \
  -i cinematic/shots_A/A2_pullback.mp4 \
  -filter_complex "[0:v]scale=1920:1080[v0];[1:v]scale=1920:1080[v1];[2:v]scale=1920:1080[v2];[v0][v1][v2]concat=n=3:v=1:a=0[outv]" \
  -map "[outv]" -c:v libx264 -pix_fmt yuv420p -crf 18 \
  cinematic/final/PlugInParasite_v2_40s.mp4
```

That's the portfolio-ready first cut. Audio mix is a separate pass
(see `edit_pipeline_v2.md`).

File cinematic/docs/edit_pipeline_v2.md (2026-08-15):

# Edit Pipeline V2 — Bookend Track A + Clay HERO

Companion to `storyboard_v2.md`. The original `edit_pipeline.md` covers
the full 8-cut 42-second hybrid. This file documents the simpler 3-cut
bookend version (40 sec total) which can be assembled with pure ffmpeg
— no DaVinci required for the first portfolio cut.

---

## Inputs

```
cinematic/shots_A/A1_forest_establishing.mp4   1920×1080  5s   Kling
cinematic/shots_v2/HERO_v12_30s.mp4            1280×720  30s   Rhino clay
cinematic/shots_A/A2_pullback.mp4              1920×1080  5s   Kling
```

The clay HERO is 1280×720; Kling output is 1920×1080. ffmpeg will
upscale the clay to 1920×1080 with lanczos before concat.

---

## ffmpeg concat (one-shot)

```bash
# From repo root:
ffmpeg -y \
  -i cinematic/shots_A/A1_forest_establishing.mp4 \
  -i cinematic/shots_v2/HERO_v12_30s.mp4 \
  -i cinematic/shots_A/A2_pullback.mp4 \
  -filter_complex "\
[0:v]scale=1920:1080:flags=lanczos,setsar=1,fps=24[v0];\
[1:v]scale=1920:1080:flags=lanczos,setsar=1,fps=24[v1];\
[2:v]scale=1920:1080:flags=lanczos,setsar=1,fps=24[v2];\
[v0][v1][v2]concat=n=3:v=1:a=0[outv]" \
  -map "[outv]" \
  -c:v libx264 -pix_fmt yuv420p -crf 18 -preset slow \
  cinematic/final/PlugInParasite_v2_40s.mp4
```

Output:
- 1920×1080 24fps 40s ~5-10MB H.264
- No audio yet (added in pass 2 below)

---

## Audio pass (after Kling shots arrive)

Two tracks:
1. **Music bed** — minimal cinematic ambient. Either Suno, Epidemic Sound,
   or a free Creative Commons piece. Recommended: 40-sec piece with one
   gentle swell around the 8-second mark (right when the HERO clay
   starts spreading).
2. **Forest ambient** — light wind + distant birds during A1/A2,
   silenced during the clay HERO middle.

Mix with:
```bash
ffmpeg -y \
  -i cinematic/final/PlugInParasite_v2_40s.mp4 \
  -i cinematic/audio/music_bed.mp3 \
  -i cinematic/audio/ambient_forest.mp3 \
  -filter_complex "[1:a]volume=0.7[m];\
[2:a]volume=0.4,atrim=0:5,apad,atrim=0:40[a1];\
[2:a]volume=0.4,atrim=0:5,adelay=35s|35s,apad,atrim=0:40[a2];\
[a1][a2]amix=inputs=2[ambient];\
[m][ambient]amix=inputs=2:duration=longest[outa]" \
  -map 0:v -map "[outa]" \
  -c:v copy -c:a aac -b:a 192k -ac 2 \
  -loudnorm I=-14 \
  cinematic/final/PlugInParasite_v2_40s_audio.mp4
```

Loudness normalized to -14 LUFS (Instagram / LinkedIn standard).

---

## Title cards (optional pass 3 — DaVinci or ffmpeg drawtext)

If you want a project name overlay, easiest path is DaVinci:
- 0:00–0:02 fade-in "PLUG-IN PARASITE"
- 0:38–0:40 fade-in "caglarcelik architects · 2026"

Or pure ffmpeg drawtext (no DaVinci):
```bash
ffmpeg -y -i cinematic/final/PlugInParasite_v2_40s_audio.mp4 \
  -vf "drawtext=fontfile=/path/to/InterTight-SemiBold.ttf:\
text='PLUG-IN PARASITE':fontcolor=white@0.9:fontsize=42:\
x=(w-text_w)/2:y=h-150:\
enable='between(t,0.5,2.0)':alpha='if(lt(t,0.5),0,if(lt(t,0.8),(t-0.5)/0.3,if(lt(t,1.7),1,(2.0-t)/0.3)))'" \
  -c:a copy \
  cinematic/final/PlugInParasite_v2_40s_titled.mp4
```

(Path the font file accordingly; on this machine fonts live in
`<your-fonts-dir>/` or via FontBase.)

---

## Output naming convention

```
PlugInParasite_v2_40s.mp4           video only (no audio)
PlugInParasite_v2_40s_audio.mp4     +music +ambient, -14 LUFS
PlugInParasite_v2_40s_titled.mp4    +intro/outro cards
PlugInParasite_v2_40s_FINAL.mp4     master, includes everything
```

Social variants (after FINAL):
- `_IG_9x16.mp4` — 1080×1920 vertical, parasol must stay centered
- `_LinkedIn.mp4` — copy of FINAL
- `_Twitter.mp4` — same as FINAL but capped at 2:20 (auto-loops)

---

## Track A still missing?

If Kling/Luma submission delayed, ship the **clay HERO alone** as a
single-piece portfolio asset:

```bash
ffmpeg -y -i cinematic/shots_v2/HERO_v12_30s.mp4 \
  -vf "scale=1920:1080:flags=lanczos,setsar=1" \
  -c:v libx264 -pix_fmt yuv420p -crf 18 -preset slow \
  cinematic/final/PlugInParasite_clay_30s_1080p.mp4
```

A 30-second clean clay deploy/retract loop. Fine for LinkedIn /
Instagram on its own.

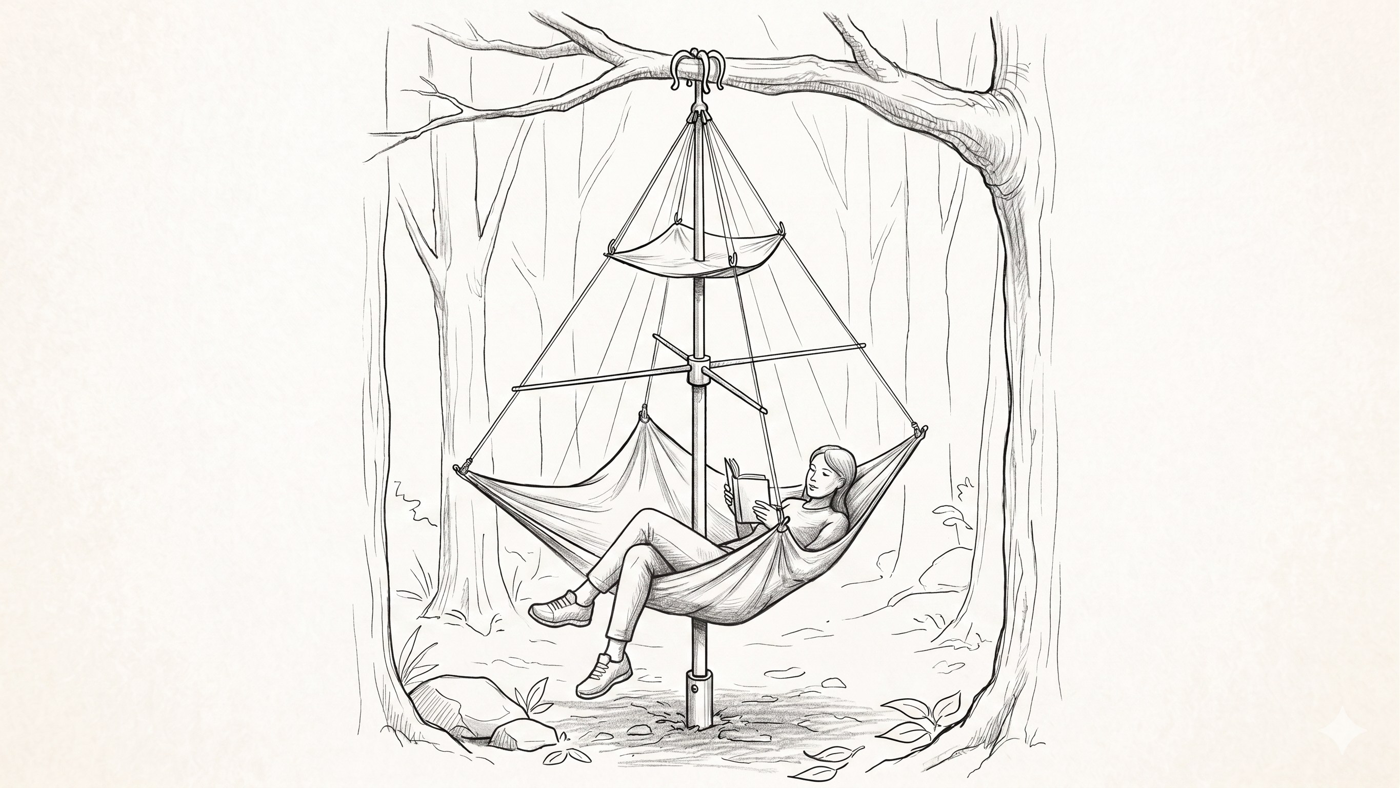
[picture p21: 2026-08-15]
cinematic/concept_boards/04_OPEN.jpg

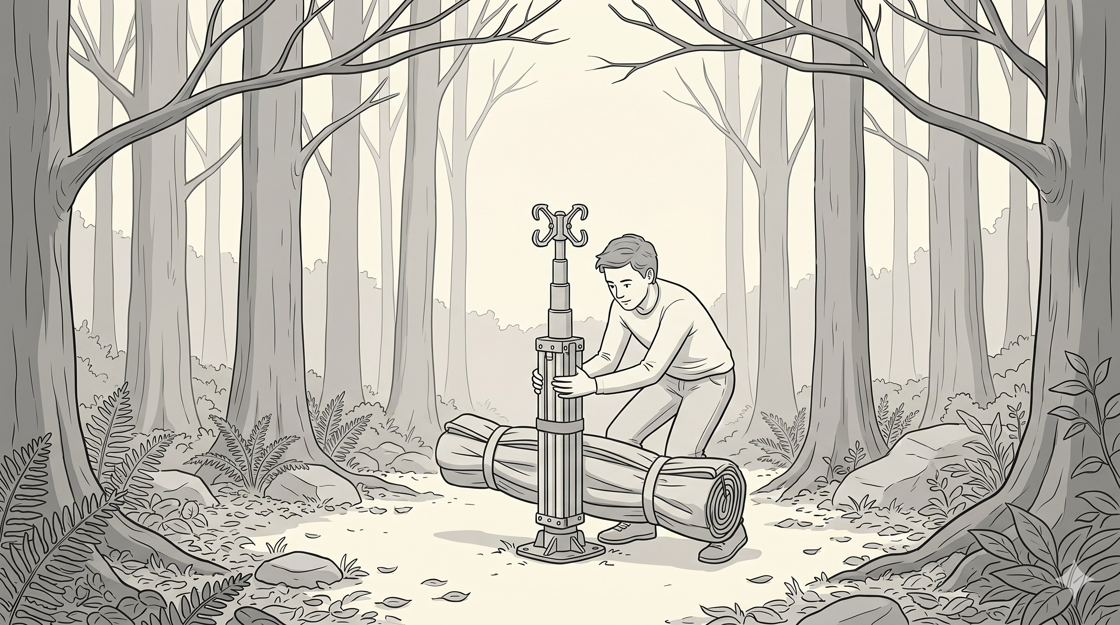
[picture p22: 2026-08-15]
cinematic/concept_boards/07_SETDOWN.jpg

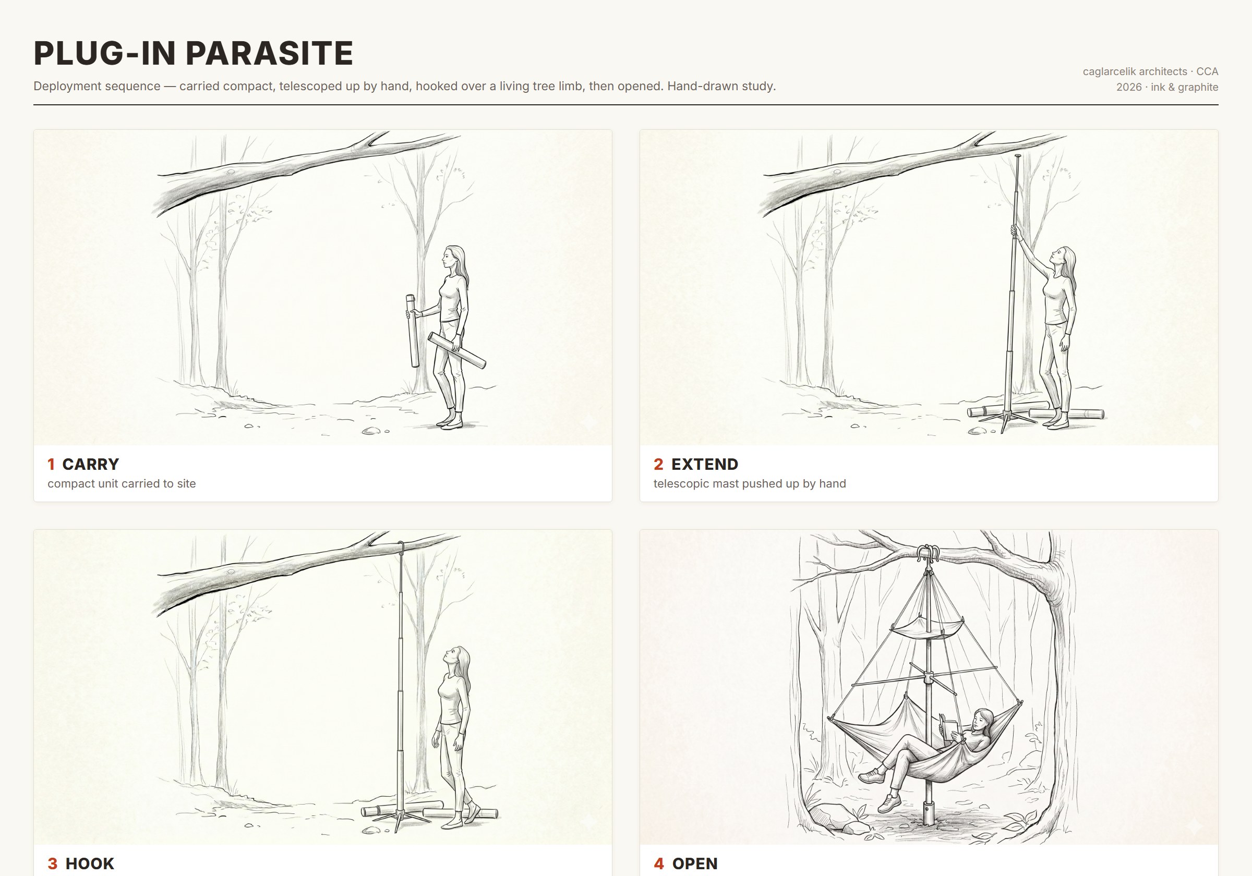
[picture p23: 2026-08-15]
cinematic/concept_boards/PlugInParasite_deployment_AI.jpg

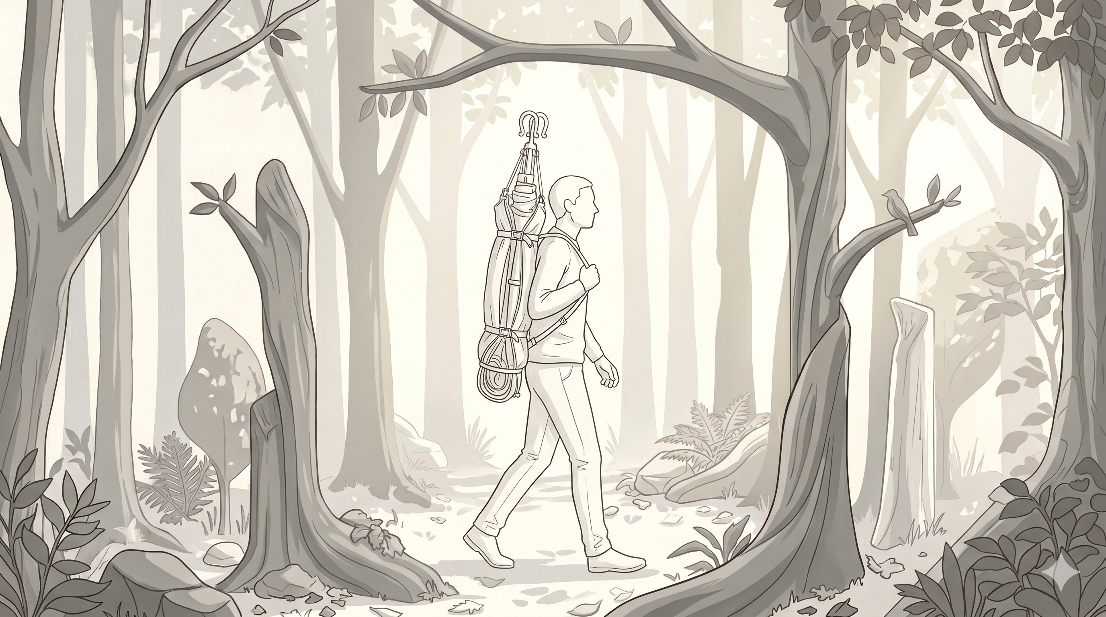
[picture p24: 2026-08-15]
cinematic/concept_boards/06_BACKPACK.jpg

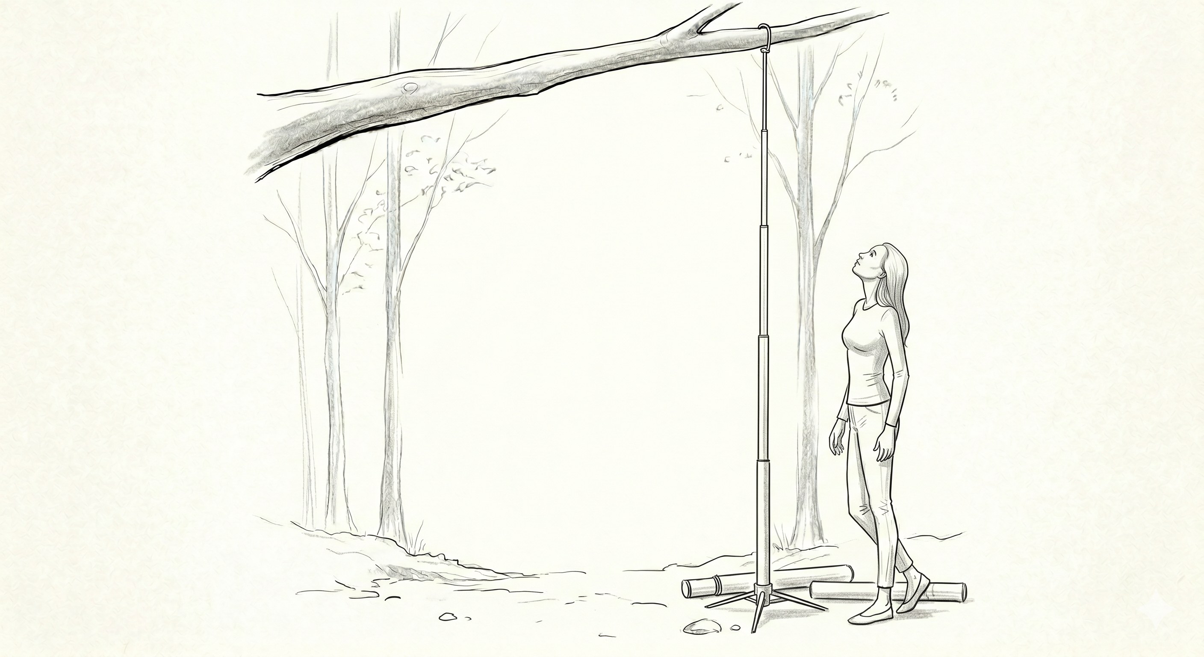
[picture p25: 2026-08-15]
cinematic/concept_boards/03_HOOK.jpg

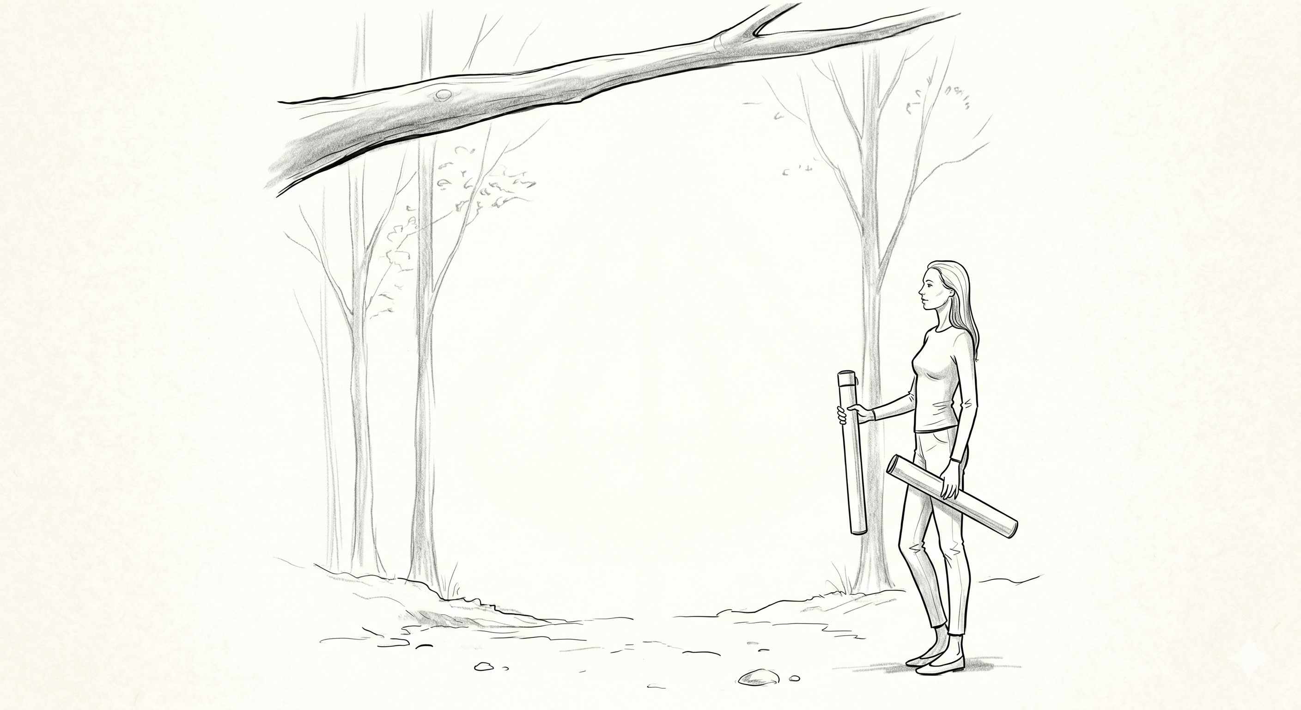
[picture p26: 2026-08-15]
cinematic/concept_boards/01_CARRY.jpg

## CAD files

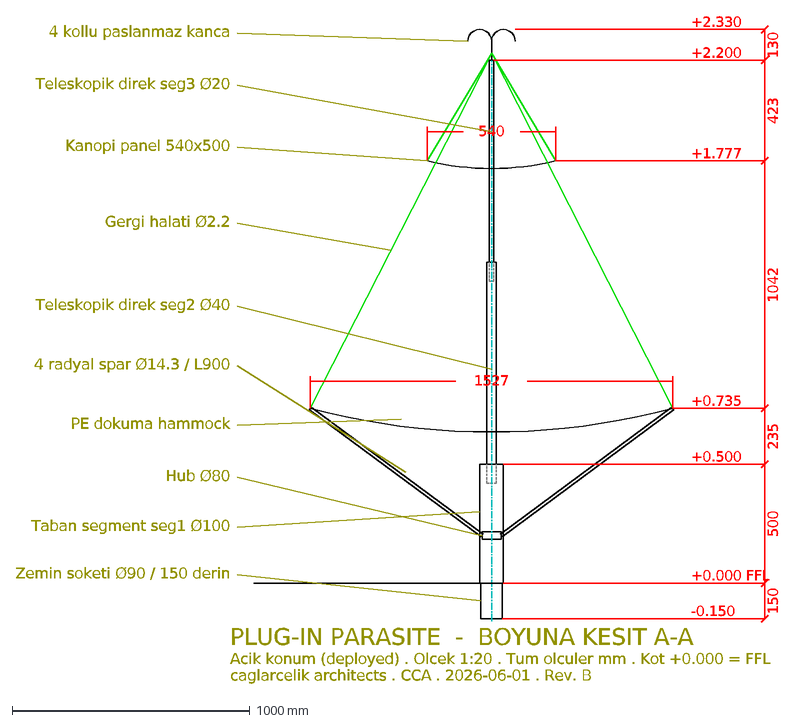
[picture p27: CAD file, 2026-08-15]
cinematic/drawings/PlugInParasite_section.dxf
130
423
1042
235
500
150
+2.330
+2.200
+1.777
+0.735
+0.500
+0.000 FFL
-0.150
1527
540
4 kollu paslanmaz kanca
Teleskopik direk seg3 Ø20
Kanopi panel 540x500
Gergi halati Ø2.2
Teleskopik direk seg2 Ø40
4 radyal spar Ø14.3 / L900
PE dokuma hammock
Hub Ø80
Taban segment seg1 Ø100
Zemin soketi Ø90 / 150 derin
PLUG-IN PARASITE - BOYUNA KESIT A-A
Acik konum (deployed) . Olcek 1:20 . Tum olculer mm . Kot +0.000 = FFL
caglarcelik architects . CCA . 2026-06-01 . Rev. B

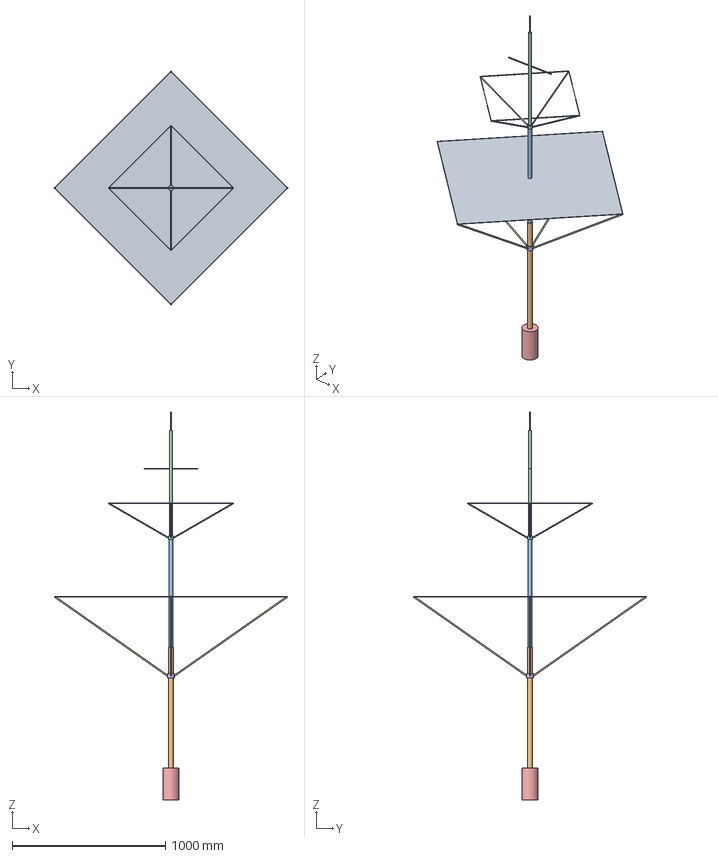
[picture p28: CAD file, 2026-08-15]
PlugInParasite.step
1523.1 x 1523.1 x 2530.0 mm
Rigging
Storage

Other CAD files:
PlugInParasite.3dm
PlugInParasite.f3d

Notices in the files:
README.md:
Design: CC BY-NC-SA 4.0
